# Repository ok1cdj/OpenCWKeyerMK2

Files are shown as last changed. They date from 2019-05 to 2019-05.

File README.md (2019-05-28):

# OpenCWKeyerMK2

Hardware for K3NG Arduino keyer https://github.com/k3ng/k3ng_cw_keyer

KIT is available from https://www.hamshop.cz/open-cw-keyer-c27/open-cw-keyer-i196/

Documentation https://github.com/ok1cdj/OpenCWKeyerMK2/wiki

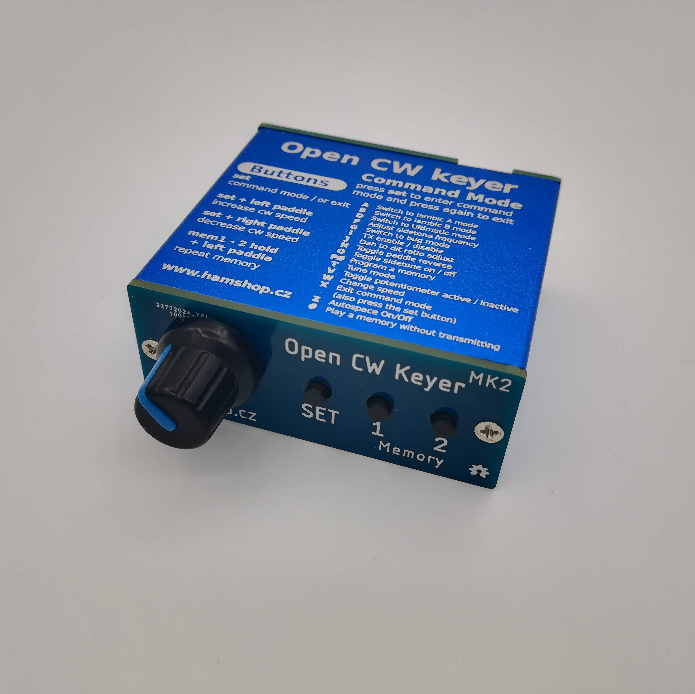
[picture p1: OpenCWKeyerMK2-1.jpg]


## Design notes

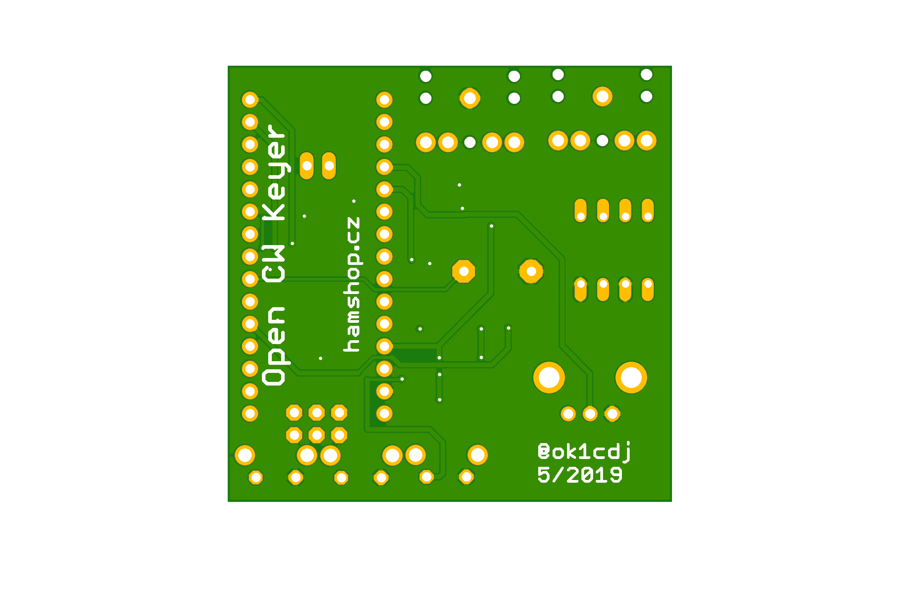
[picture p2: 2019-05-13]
open_cw_keyer_mk2_v30-bottom.png

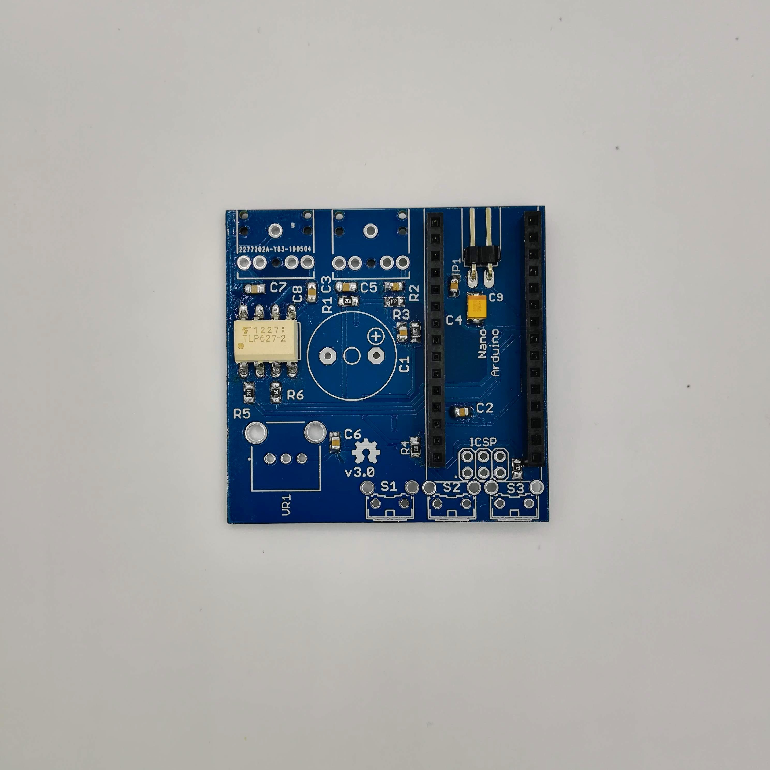
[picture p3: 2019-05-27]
images/opencwkeyermk2-jumper.jpg

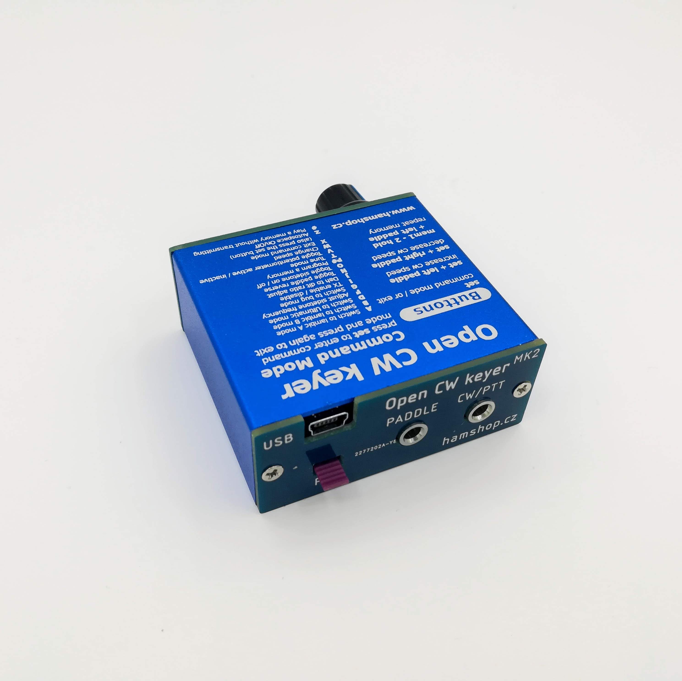
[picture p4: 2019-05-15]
OpenCWKeyerMK2-2.jpg

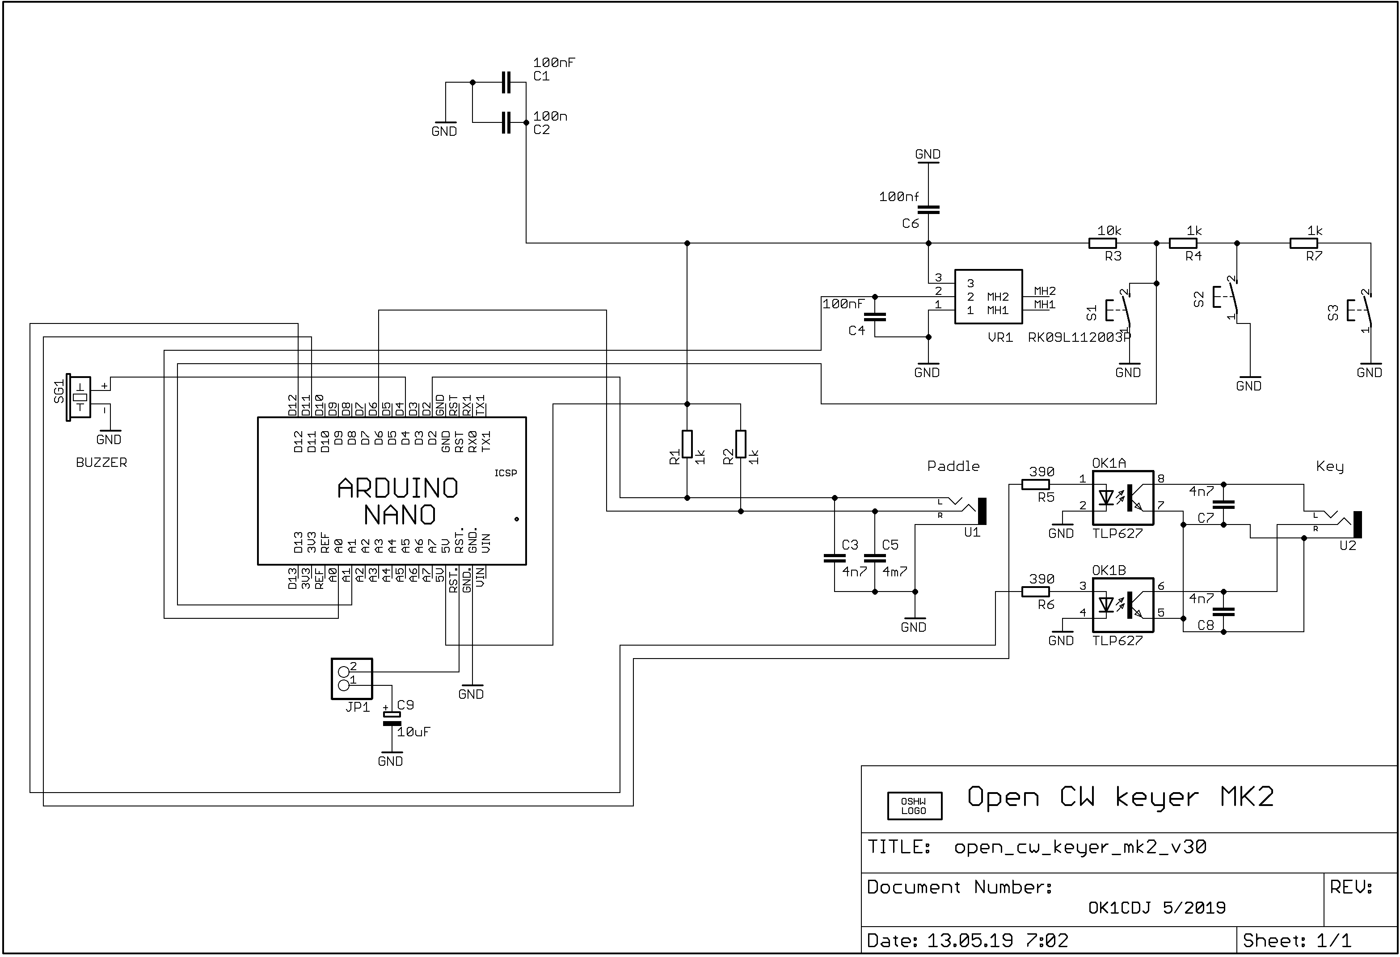
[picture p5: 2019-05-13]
opencwkeyermk2v30-sch.png

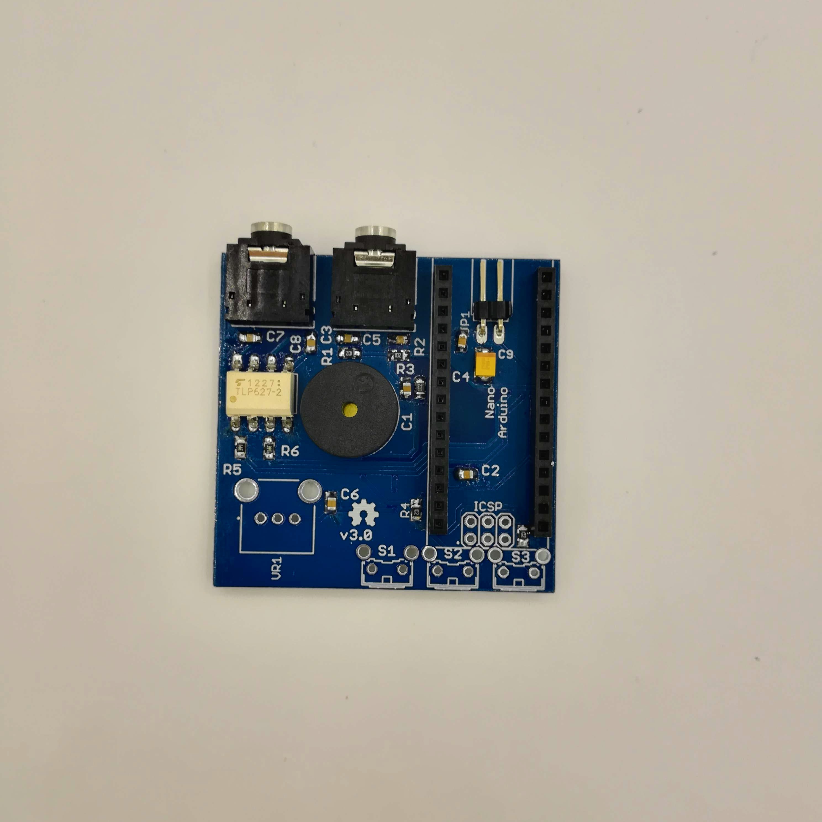
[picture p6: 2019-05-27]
images/opencwkeyermk2-buzzer.jpg

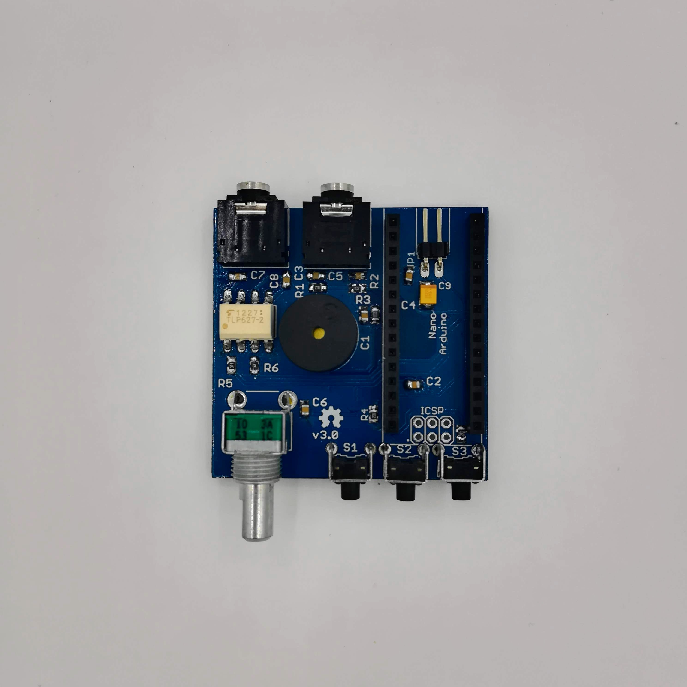
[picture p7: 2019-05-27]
images/opencwkeyermk2-pot.jpg

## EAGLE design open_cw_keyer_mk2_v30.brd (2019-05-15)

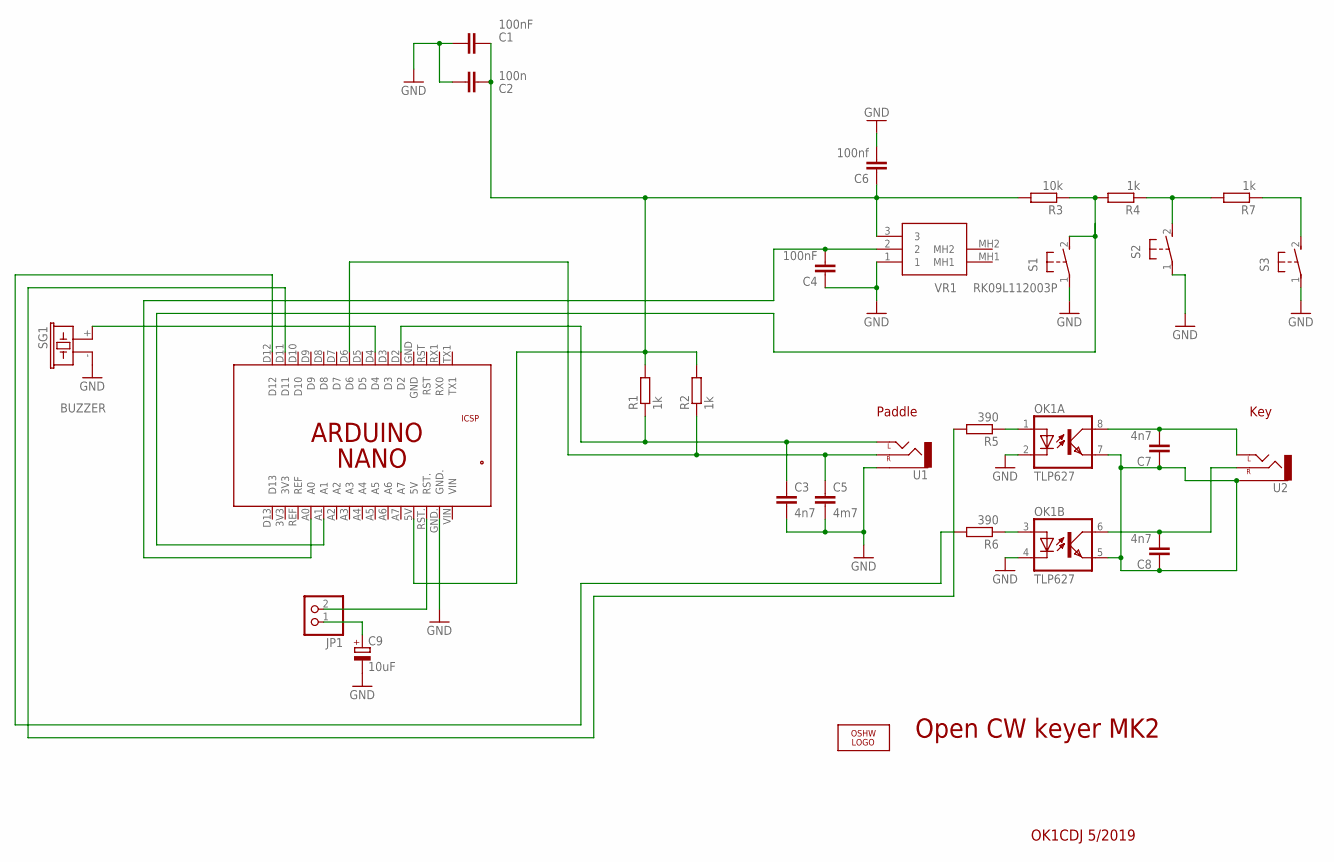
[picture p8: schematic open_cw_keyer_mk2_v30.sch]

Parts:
C1, C4: 100nF; C0805
C2: 100n; C0805
C3: 4n7; C0805
C5: 4m7; C0805
C6: 100nf; C0805
C7, C8: 4n7; C0805K
C9: 10uF; B/3528-21R
JP1: PINHD-1X2/90; 1X02/90
LOGO1: OSHW_LOGO_FILLX0150-NT; OSHW_FILLX150_NOTEXT
OK1: TLP627; DIL08
PCB1: ARDUINO_NANO
R1, R2, R4, R7: 1k; M0805
R3: 10k; M0805
R5, R6: 390; M0805
S1, S2, S3: 31-XX; B3F-31XX
SG1: BUZZER; F/CM12P
U1, U2: AUDIO-JACKPTH; AUDIO-JACK
VR1: RK09L112003P

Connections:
5V: C1.1, C2.1, C6.1, PCB1.5V, R1.2, R2.2, R3.2, VR1.3
GND: C1.2, C2.2, C3.2, C4.1, C5.2, C6.2, C9.-, OK1.2 (C), OK1.4 (C), PCB1.GND., S1.1, S2.1, S3.1, SG1.- (2), U1.SLEEVE, VR1.1
unnamed: C3.1, PCB1.D2, R1.1, U1.TIP (LEFT)
unnamed: PCB1.D4, SG1.+ (1)
unnamed: JP1.2, PCB1.RST.
unnamed: R4.1, R7.2, S2.2 (S)
unnamed: OK1.1 (A), R5.1
unnamed: OK1.3 (A), R6.1
unnamed: C9.+, JP1.1
unnamed: C7.2, OK1.8 (COL), U2.TIP (LEFT)
unnamed: C8.2, OK1.6 (COL), U2.RING (RIGHT)
unnamed: R7.1, S3.2 (S)
unnamed: C7.1, C8.1, OK1.5 (EMIT), OK1.7 (EMIT), U2.SLEEVE
unnamed: C5.1, PCB1.D6, R2.1, U1.RING (RIGHT)
unnamed: PCB1.D11, R5.2
unnamed: PCB1.D12, R6.2
POT: C4.2, PCB1.A0, VR1.2
TL: PCB1.A1, R3.1, R4.2, S1.2 (S)

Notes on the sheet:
Open CW keyer MK2
Paddle
Key
OK1CDJ 5/2019

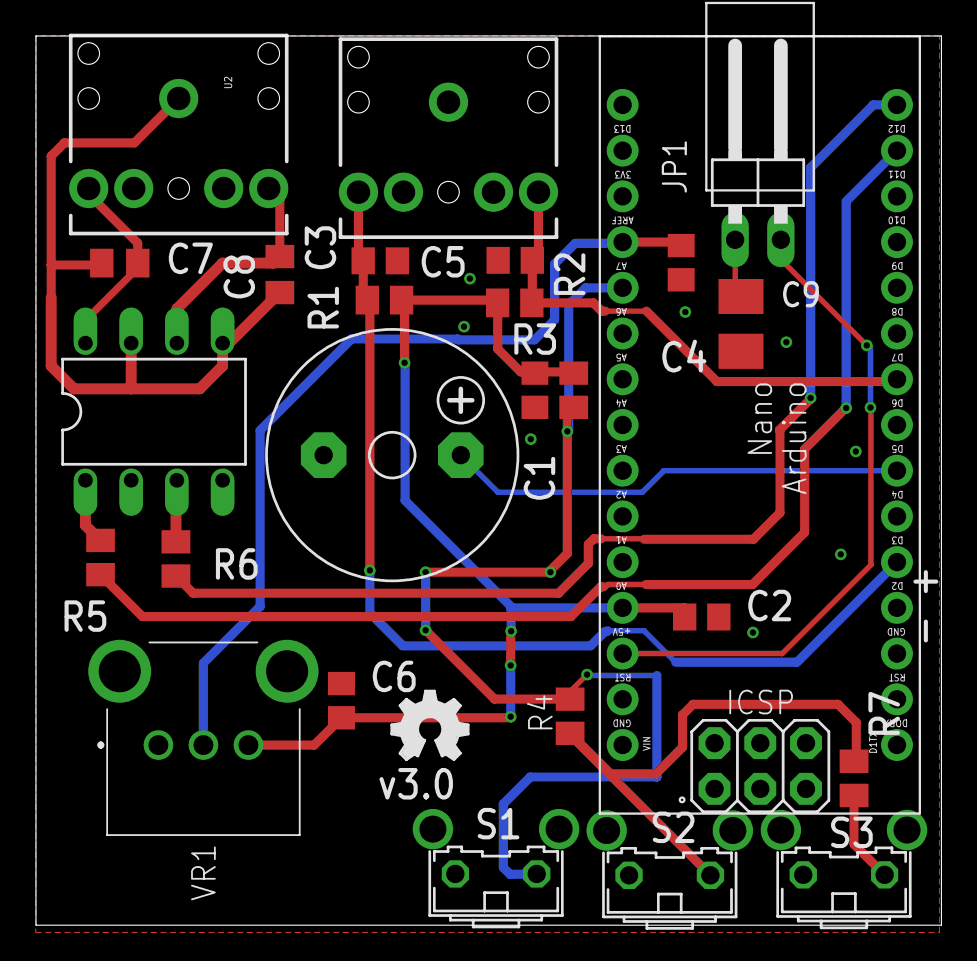
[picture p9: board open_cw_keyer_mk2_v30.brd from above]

Board: 2 copper layers, 50.3 x 49.4 mm, 27 parts (0 on the bottom side), 18 nets.

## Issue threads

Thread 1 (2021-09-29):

Winkey emulation

henryflower, 2021-09-29:
Hi,

I have noticed the following with my Open CW Keyer MK2: I have compiled and uploaded the firmware without any changes to options:

- in DXLog, it recognises the device as a Winkey on startup but output fails; after re-initialising from within the DXLog interfaces menu it works perfectly.
- in Win-Test it fails to recognise it as a Winkey, consequently, no CW output.
- The test software that K1EL provides ( [WKscan and WKtest](https://www.k1elsystems.com/softwareX.html) ) also fails to recognise the device as a Winkey.

Is there an option in the Arduino header files that I need to set to get it working without flaws or am I missing another point somewhere?

Thanks.

ok1cdj, 2021-10-02:
Hi, do you have jumper on back side of keyer pluged in ?
and check this config:
`#define OPTION_WINKEY_STRICT_HOST_OPEN               // require an admin host open Winkey command before doing any other commands
#define OPTION_WINKEY_2_SUPPORT                      // comment out to revert to Winkey version 1 emulation
#define OPTION_WINKEY_INTERRUPTS_MEMORY_REPEAT
//#define OPTION_WINKEY_UCXLOG_9600_BAUD              // use this only with UCXLog configured for Winkey 9600 baud mode
#define OPTION_WINKEY_2_HOST_CLOSE_NO_SERIAL_PORT_RESET  // (Required for Win-Test to function)
// #define OPTION_WINKEY_FREQUENT_STATUS_REPORT         // activate this to make Winkey emulation play better with RUMlog and RUMped
#define OPTION_WINKEY_IGNORE_LOWERCASE               // Enable for typical K1EL Winkeyer behavior (use for SkookumLogger version 1.10.14 and prior to workaround "r" bug)`

henryflower, 2021-10-02:
Hi,

I did not realise that the jumper was needed. With the jumper plugged in it works as expected with all the different programmes that I mentioned before. Thanks for your help.

ok1cdj, 2021-10-02:
Jumer is needed due diffrent  RTS/DTR usage of  the software. Remove jumper only when FW update is needed.

73 Ondra OK1CDJ

Closed 2021-10-02.

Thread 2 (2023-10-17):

Reset Open CW Keyer

DL1ABR, 2023-10-17:
Hi everybody,
I think I did something wrong via the buttons.
My fingers were too fast ;-)
My "Open CW Keyer MK2" says in "WKdemo"
openComm: Success
Attach WK: No Echo
The Keyer beeps HI when I power it on.
Bit it shows no other reactions either via buttons nor via WKdemo.
Any hints??
Does anybody know how to reset the keyer??
vy 73 de Franz

ok1cdj, 2023-10-19:
Which version of SW ? How about reset  ? You need to have switch plugged in for normal use.

73 Ondra

DL1ABR, 2023-10-19:
Hi Ondra.
After switching on the keyer it reports CW „HI“
the COM port can be opened, otherwise "Error: WK not Open".
I have no access to the Keyer anymore.
I may have changed something while typing on the keys...
Is it possible to „reset to factory settings“??
The switch – you mean PRG jumper?
This jumper is open. No jumper.

Vy 73, Franz - DL1ABR

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

ok1cdj, 2023-10-19:
When you use winkey, the **jumper on back side of keyer must be installed**.

73 Ondra

DL1ABR, 2023-10-20:
Hi, Ondra,

a little peace of thin wire helped.
Because I have no jumper.
And nobody has a 2 mm-jumper around here.
So a thin wire must do.

When I want to switch to „IAMBIC MODE A“ I must

1.	Take jumper off
2.	Connect to WKdemo
3.	Type „\a“ and „ENTER“
4.	And type „EXIT“ „ENTER“
5.	Disconnect from WKdemo

Is that correct??

vy 73 de

Franz – DL1ABR

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

ok1cdj, 2023-10-22:
The jumper will be off only when you upgrading firmware.  If you set Iambic A from winkey is it possible, but you need to have it connect as winkey.  Use command mode by button,  read the manual:
https://github.com/k3ng/k3ng_cw_keyer/wiki

73 Ondra OK1CDJ

DL1ABR, 2023-10-24:
Thank you so much Ondra!!
Step by step I learn to use the keyer 😊
vy 73 de

Franz DL1ABR

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

Closed 2023-11-28.

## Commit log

2019-05-13 Schematic and PCB pictures
2019-05-15 Eagle files for main board
    [open_cw_keyer_mk2_v30.brd, open_cw_keyer_mk2_v30.sch]
2019-05-16 Front and rear panels
    [panel-b.brd, panel.brd]
